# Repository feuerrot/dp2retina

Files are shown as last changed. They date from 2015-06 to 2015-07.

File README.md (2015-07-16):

# dp2retina

Nach [diesem Blogpost](http://emerythacks.blogspot.de/2013/04/connecting-ipad-retina-lcd-to-pc.html) und Displaydatenblatt gebaut: Ein passiver Adapter von Displayport auf embedded Displayport.
Zusätzlich: zwei MAX17129 für die 12 Kanäle der Hintergrundbeleuchtung + ein ATTiny45 mit VUSB-Support für HintergrundbeleuchtungsPWM.

## Projektstatus
Das Platinenlayout funktioniert. Der Connector für das Display ist nicht schön zu löten und die Schaltreglerkomponenten mittels Lötkolben auch nicht so.

## Todo
* größere Platine
 * seitliche Anschlüsse
 * Buttons zur Helligkeitsregelung
* ein Gehäuse
 * 3D-Druck ist zu klein -> Lasercutter&Plexiglas?

## Layout und so

### Schaltplan
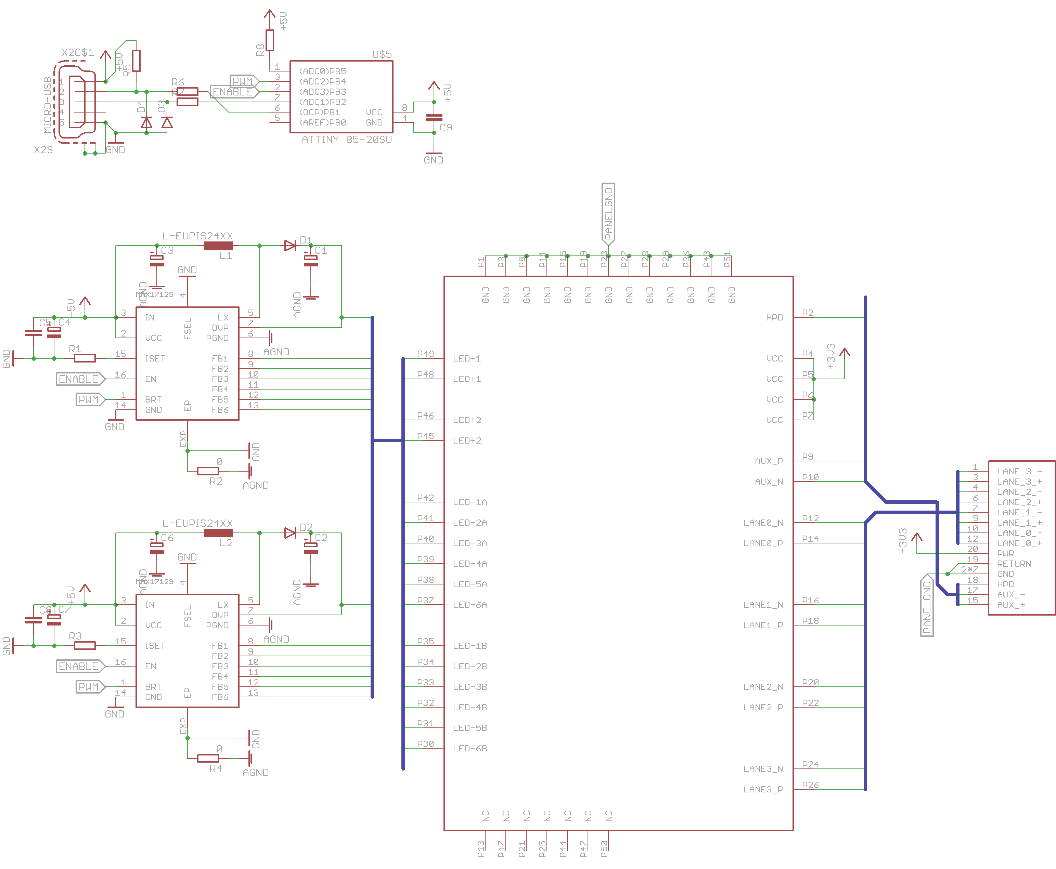
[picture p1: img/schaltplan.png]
Schaltplan der Beaconschaltung


### Layout
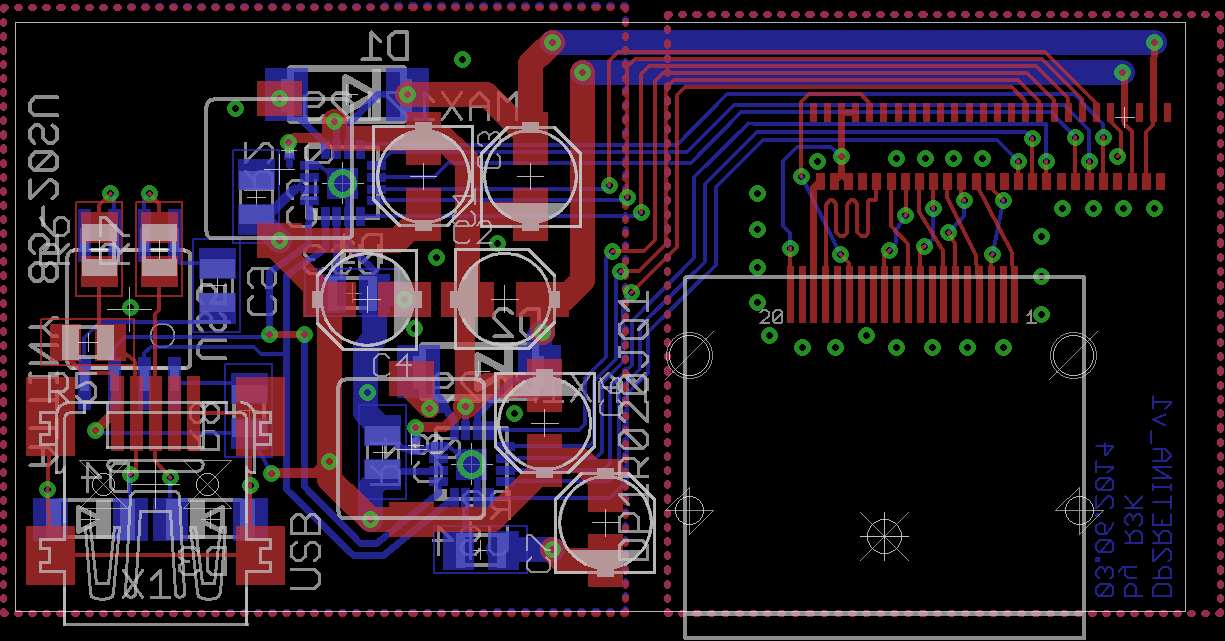
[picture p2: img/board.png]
Layout der Beaconschaltung


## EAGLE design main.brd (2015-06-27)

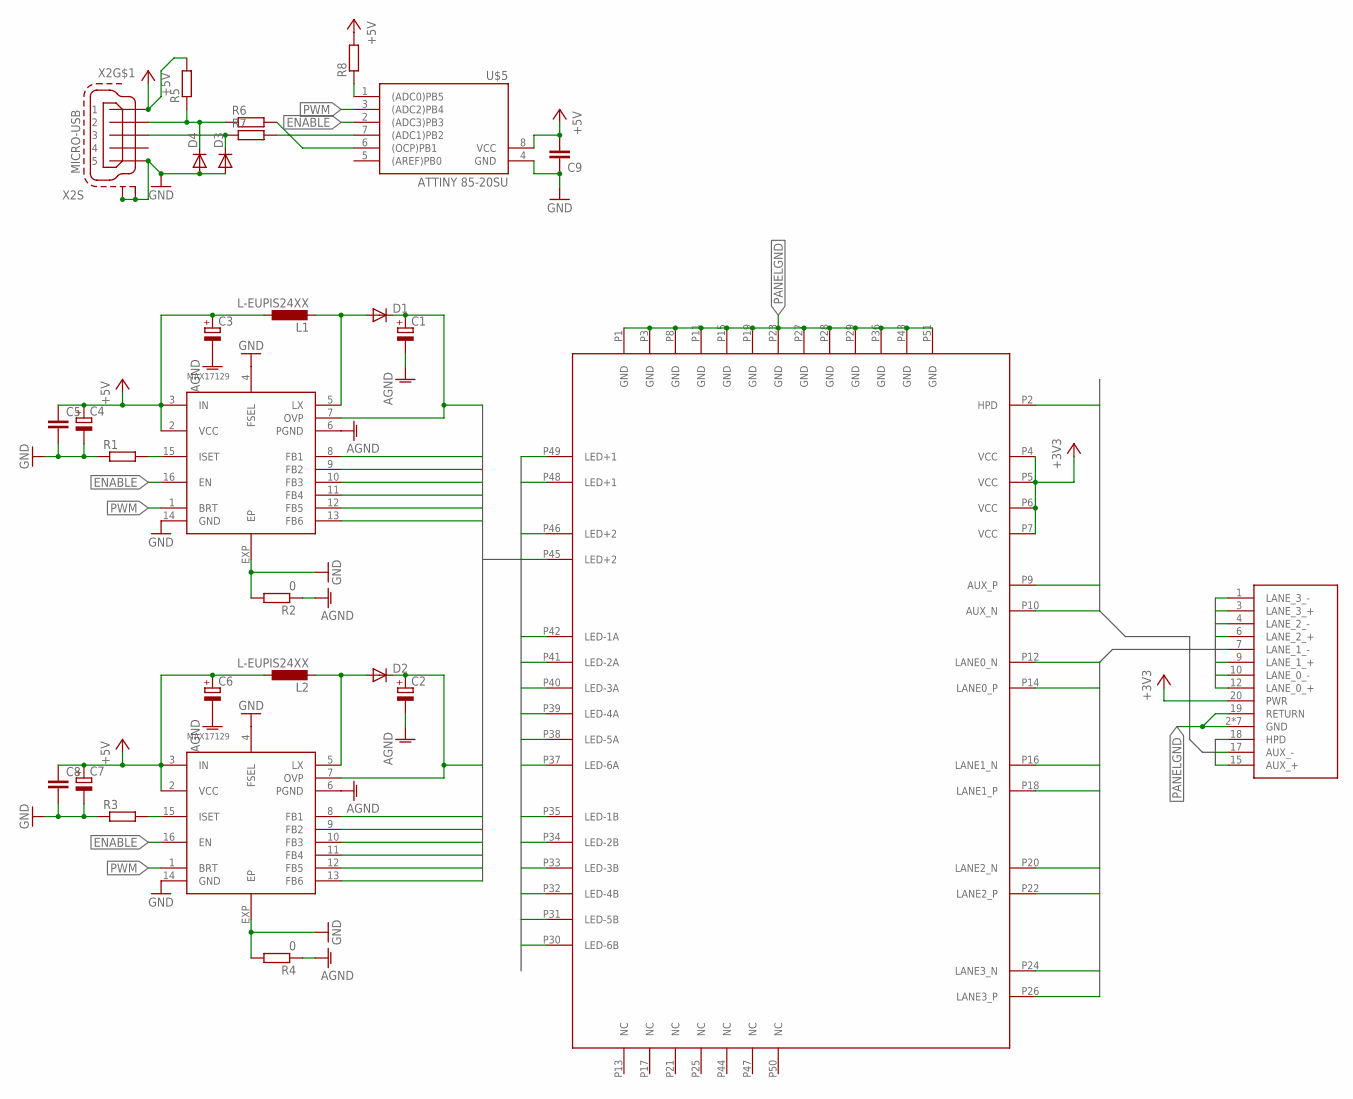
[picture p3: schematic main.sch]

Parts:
C1, C2, C3, C4, C6, C7: CPOL-EUB; PANASONIC_B
C5, C8, C9: C-EUC0805; C0805
D1, D2: DIODE-DO214AA; DO214AA
D3, D4: DIODE-MINIMELF; MINIMELF
L1, L2: L-EUPIS24XX; PIS24XX
R1, R3: R-EU_M0805; M0805
R2, R4: 0; R0201
R5, R6, R7, R8: R-EU_R0805; R0805
U$1: IPAD3-CONN; MOLEX502250-5191
U$2: DP1R020JQ1SINK; DP1R020JQ1
U$3, U$4: MAX17129; QFN16-4X4
U$5: ATTINY 85-20SU; SOIC8
X2: MICRO-USB; SMD

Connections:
+3V3: U$1.P4 (VCC), U$1.P5 (VCC), U$1.P6 (VCC), U$1.P7 (VCC), U$2.20 (PWR)
AGND: C1.-, C2.-, C3.-, C6.-, R2.1, R4.1, U$3.6 (PGND), U$4.6 (PGND)
AUX_N: U$1.P10 (AUX_N), U$2.17 (AUX_-)
AUX_P: U$1.P9 (AUX_P), U$2.15 (AUX_+)
ENABLE: U$3.16 (EN), U$4.16 (EN), U$5.2 ((ADC3)PB3)
HPD: U$1.P2 (HPD), U$2.18 (HPD)
LANE0_N: U$1.P12 (LANE0_N), U$2.10 (LANE_0_-)
LANE0_P: U$1.P14 (LANE0_P), U$2.12 (LANE_0_+)
LANE1_N: U$1.P16 (LANE1_N), U$2.7 (LANE_1_-)
LANE1_P: U$1.P18 (LANE1_P), U$2.9 (LANE_1_+)
LANE2_N: U$1.P20 (LANE2_N), U$2.4 (LANE_2_-)
LANE2_P: U$1.P22 (LANE2_P), U$2.6 (LANE_2_+)
LANE3_N: U$1.P24 (LANE3_N), U$2.1 (LANE_3_-)
LANE3_P: U$1.P26 (LANE3_P), U$2.3 (LANE_3_+)
LED_N_A_1: U$1.P42 (LED-1A), U$3.8 (FB1)
LED_N_A_2: U$1.P41 (LED-2A), U$3.11 (FB4)
LED_N_A_3: U$1.P40 (LED-3A), U$3.9 (FB2)
LED_N_A_4: U$1.P39 (LED-4A), U$3.12 (FB5)
LED_N_A_5: U$1.P38 (LED-5A), U$3.10 (FB3)
LED_N_A_6: U$1.P37 (LED-6A), U$3.13 (FB6)
LED_N_B_1: U$1.P35 (LED-1B), U$4.8 (FB1)
LED_N_B_2: U$1.P34 (LED-2B), U$4.11 (FB4)
LED_N_B_3: U$1.P33 (LED-3B), U$4.9 (FB2)
LED_N_B_4: U$1.P32 (LED-4B), U$4.12 (FB5)
LED_N_B_5: U$1.P31 (LED-5B), U$4.10 (FB3)
LED_N_B_6: U$1.P30 (LED-6B), U$4.13 (FB6)
LED_P_1: C1.+, D1.C, U$1.P48 (LED+1), U$1.P49 (LED+1), U$3.7 (OVP)
LED_P_2: C2.+, D2.C, U$1.P45 (LED+2), U$1.P46 (LED+2), U$4.7 (OVP)
unnamed: R1.2, U$3.15 (ISET)
unnamed: R3.2, U$4.15 (ISET)
unnamed: D1.A, L1.1 (2), U$3.5 (LX)
unnamed: D2.A, L2.1 (2), U$4.5 (LX)
unnamed: R6.2, U$5.6 ((OCP)PB1)
unnamed: R7.2, U$5.7 ((ADC1)PB2)
unnamed 36: D3.C, R7.1, X2.3; also elsewhere on the board
unnamed 37: D4.C, R5.1, R6.1, X2.2; also elsewhere on the board
unnamed: R8.1, U$5.1 ((ADC0)PB5)
PANELGND: U$1.P1 (GND), U$1.P3 (GND), U$1.P8 (GND), U$1.P11 (GND), U$1.P15 (GND), U$1.P19 (GND), U$1.P23 (GND), U$1.P27 (GND), U$1.P28 (GND), U$1.P29 (GND), U$1.P36 (GND), U$1.P43 (GND), U$1.P51 (GND), U$2.2 (GND), U$2.5 (GND), U$2.8 (GND), U$2.11 (GND), U$2.13 (GND), U$2.14 (GND), U$2.16 (GND), U$2.19 (RETURN)
PWM: U$3.1 (BRT), U$4.1 (BRT), U$5.3 ((ADC2)PB4)

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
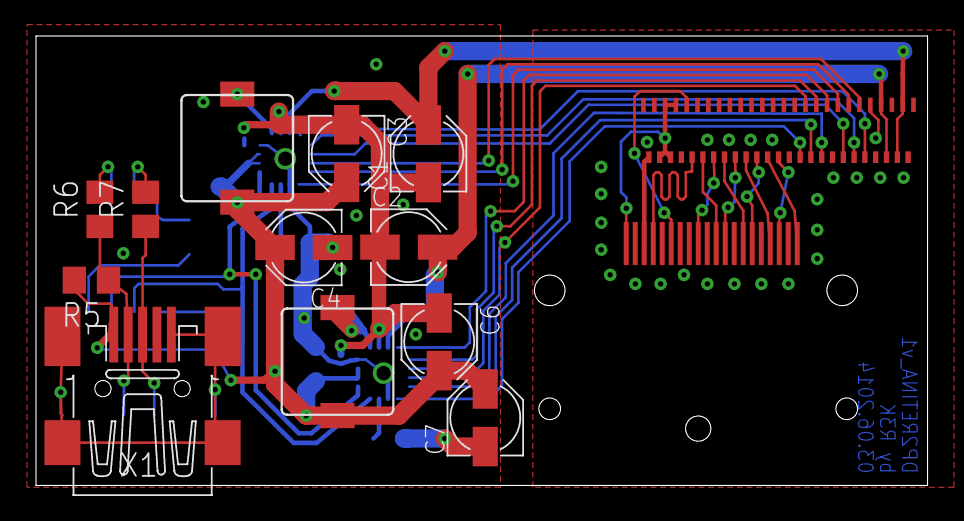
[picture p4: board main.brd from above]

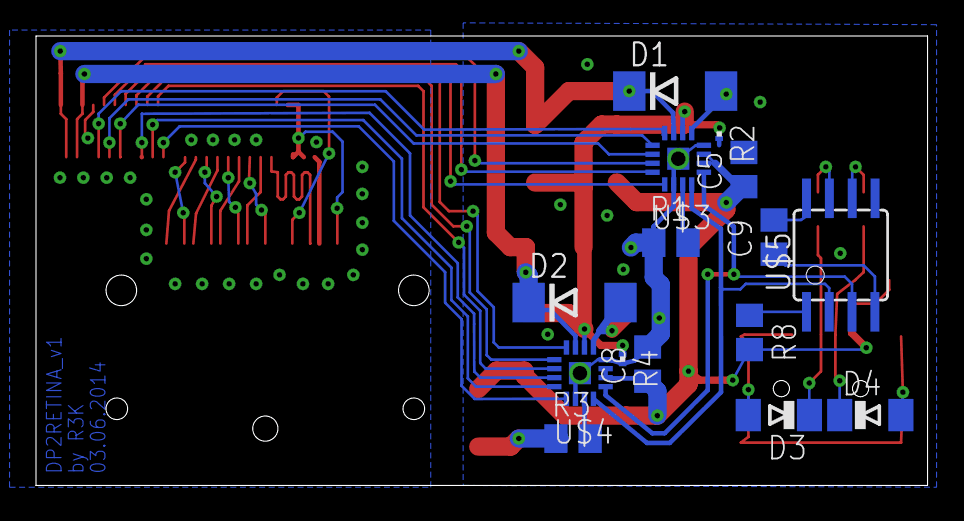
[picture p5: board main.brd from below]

Board: 2 copper layers, 49.5 x 25.0 mm, 29 parts (15 on the bottom side), 43 nets.

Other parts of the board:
X1: USB; 32005-201

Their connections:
unnamed 36: X1.3; also elsewhere on the board
unnamed 37: X1.2; also elsewhere on the board
